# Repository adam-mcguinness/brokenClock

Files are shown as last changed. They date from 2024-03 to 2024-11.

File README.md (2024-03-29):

# Broken Clock IRL

This is an attempt to bring a project by PierreMarTich to life in the real world. After seeing his absolutely "terrible" [project](https://www.reddit.com/r/badUIbattles/comments/r3q1tl/they_say_that_even_a_broken_clock_is_right_twice/) on [r/badUIbattles](https://www.reddit.com/r/badUIbattles/) I knew I needed one on my wall. 

You can find his original project [here](https://github.com/PierreMarTich/Broken_clock) and I must give him full credit for inspiring this idea.
# Code

## Image Generation
Wrote some trash python with a little help from ChatGPT and we are in business.

Vars you can play with:

| Variable Name | Type | Default Value | Description |
|---|---|---|---|
| `style` | bool | `False` | Type of clock design. choose from `'standard'`, `'notch'`, `'cutout'`. |
| `clock_face` | bool | `False` | Enable drawing the clock face. |
| `clock_face_face_color` | string | `'none'` | Not used currently. |
| `clock_face_line_width` | int | `2` | Line width of the clock face edge. |
| `add_quarter_hour_markers` | bool | `True` | Enable drawing quarter-hour markers. |
| `quarter_hour_line_color` | string | `'white'` | Not used currently. |
| `quarter_hour_line_length` | float | `0.1` | Length of the quarter-hour marker lines. |
| `quarter_hour_line_width` | int | `1` | Line width of the quarter-hour markers. |
| `quarter_hour_line_offset` | float | `0.95` | Offset from the center for quarter-hour markers. |
| `add_5_minute_markers` | bool | `False` | Enable drawing 5-minute markers. |
| `five_minute_color` | string | `'white'` | Not used currently. |
| `five_minute_line_length` | float | `0.075` | Length of the 5-minute marker lines. |
| `five_minute_line_width` | float | `0.5` | Line width of the 5-minute markers. |
| `five_minute_line_offset` | float | `0.95` | Offset from the center for 5-minute markers. |
| `add_minute_markers` | bool | `False` | Enable drawing 1-minute markers. |
| `minute_line_color` | string | `'white'` | Color of the minute markers. |
| `minute_line_length` | float | `0.05` | Length of the minute marker lines. |
| `minute_line_width` | float | `0.25` | Line width of the minute markers. |
| `minute_line_offset` | float | `0.95` | Offset from the center for minute markers. |
| `hand_color` | string | `'white'` | Not used currently. |
| `hour_hand_length` | float | `0.5` | Length of the hour hand. |
| `hour_hand_width` | int | `2` | Width of the hour hand. |
| `minute_hand_length` | float | `0.8` | Length of the minute hand. |
| `minute_hand_width` | float | `1.5` | Width of the minute hand. |
| `units` | string | `'mm'` | Measurement units for layout and size. choose from `'inches'`, `'feet'`, `'cm'`, `'mm'`. |
| `grid_rows`, `grid_cols` | int, int | `24, 30` | Number of rows and columns in the grid layout. |
| `clock_diameter` | int | `30` | Diameter of each clock. |
| `spacing` | int | `10` | Spacing between clocks in the grid. |
| `outside_spacing` | int | `20` | Spacing between the dia. of the clock and the cut outline. |
| `background_color` | string | `'black'` | Not used currently. |
| `randomize_clocks` | bool | `False` | Whether to randomize the positions of the clocks. |
| `leds_per_tile` | int | `3` | Number of LEDs per tile in the mapping. |
| `width_in_tiles`, `height_in_tiles` | int, int | Calculated | Width and height of the grid in tiles, calculated. |

This also outputs the required vars and mapping to a .h file for importing to the microcontroller. After shuffling the clocks would be a major PITA to map manually.

Did alot of refactoring and now this outputs a dxf file directly for use with a plotter or laser cutter.

### **Fun Fact**: 
The chance of generating the same clock as someone else is ≈720! or greater than 1 in 2.60e1746. Meaning if you generated one every Planck time from the big bang until the heat death of the universe, you wouldn't even begin to scratch the surface of generating a duplicate. You would need another 10e1596 universe lengths to get there. 
## Arduino Sketch 
The main program is written in arduino for use with the attiny microcontroller. Main features included in the code are:
- saving and importing the LED mapping and Clock indexes from the library generated by the python code.
- 3 buttons for adjusting time with digital display utilizing the clock faces as digits.
  - hour increment button
  - minute increment button
  - second reset button

### Programing

As this is a tinyAVR 2-series, you can use the UPDI port to program the microcontroller with a single pin. There are a few things you need for this, but otherwise it is SUPER easy.
- Some sort of UART or TTL usb to serial connector. I bought [this](https://a.co/d/1Ms2zHJ) one, because usb-c.
- A 4.7kΩ resistor. It's talked about a lot more [here](https://github.com/SpenceKonde/AVR-Guidance/blob/master/UPDI/jtag2updi.md). Basically, I soldered the 4.7kΩ resistor to the TX and RX leads on the board and connected the RX to the UPDI port.  
- [megaTinyCore](https://github.com/SpenceKonde/megaTinyCore)
- Arduino IDE

Steps to flash:
1. Download and install the arduino IDE.
2. Install megaTinyCore, follow [these](https://github.com/SpenceKonde/megaTinyCore/blob/master/Installation.md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) steps.
3. Plug in usb adaptor and check Device Manager (for windows) to find the com port under ports.
4. Right-click on the com device, go to properties, port settings tab, advanced, change Latency Timer to 1.
5. Select your board in the IDE. Tools -> Board -> megaTinyCore -> "ATtiny3224/1624/1614/1604/824/814/804/424/414/404/214/204"
6. Select the com port for your usb adaptor. Tools -> Port -> "your com port from above"
7. Set the programmer this is what I used but might have to play around with it, [see docs](https://github.com/SpenceKonde/AVR-Guidance/blob/master/UPDI/jtag2updi.md#megatinycore). Tools -> Programmer -> "SerialUPDI - 230400 baud"
8. To program hook up the chip to VCC, GND, and the UPDI port to the RX on the programmer.
9. Verify the sketch, and make sure the generated .h file from the python script is in the same directory as the sketch.
10. Upload to the controller. If you are on a new arduino IDE v2 greater, you will need to use Sketch -> Upload Using Programmer.

# Hardware
## Electronics
### Microcontroller
The chosen microcontroller is an Attiny1624. This is the newer series 2 AVR from microchip. This has enough pins to interact with a RTC, 3 buttons for setting time, and control leads to address the LEDs for indicating.
### Real Time Clock
For the RTC I'm going with the accurate DS3231. It is extremely accurate and will only gain or lose about 1 minute a year. For all practical applications assuming you set your clock 2x a year for daylight savings the drift should be minimal. Especially for such an impractical piece of art.

This could also be subbed out for a DS1307 with minimal effort if the DS3231 is too pricey.
### LEDs
For the LEDs I have chosen to go with a 4000k individually addressable 5050 smd LED mounted to a 3x3 matrix pcb to allow tiling and cut down on the production costs while minimizing hand wiring.
## PCBs
### LED Matrix
This is a 3x3 tile that will be able to connect in a modular way to the ones adjacent to it for carry signal and power.

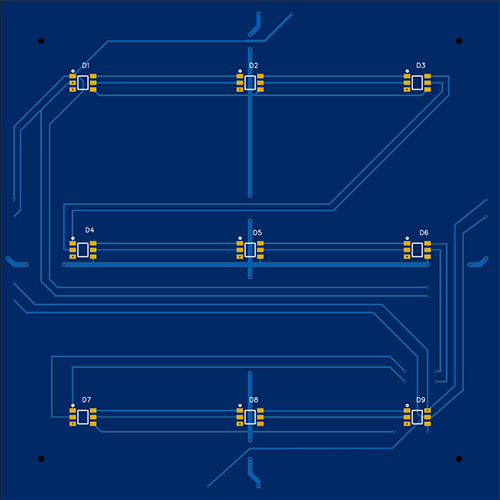
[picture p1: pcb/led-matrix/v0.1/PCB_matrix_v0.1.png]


Gerber files and schematics are available in the pcb folder.

This is v0.1 just ordered for testing. Will add a changelog here.

### Control Board
The control Board has all the other components to make this work microcontroller, RTC, buttons, etc.

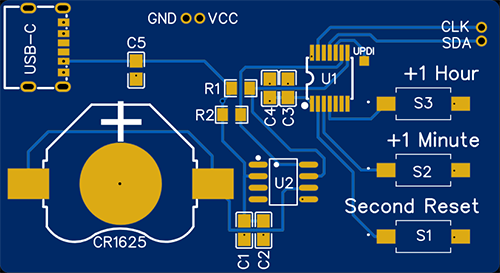
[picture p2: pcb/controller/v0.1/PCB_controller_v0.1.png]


Gerber files and schematics are available in the pcb folder.

This is v0.1 just ordered for testing. Will add a changelog here.
## Display

### Clocks
Still working out what would be best here. The running idea is to use a piece of glass or acrylic to hold a window cling or vinyl sticker for the clock faces. This should allow cheap manufacturing while providing the desired effect.
### Wall Mount/Bracket
Thinking about 3D printed parts to hold the LED Matrix boards, direct the light, and allow for modular connecting.

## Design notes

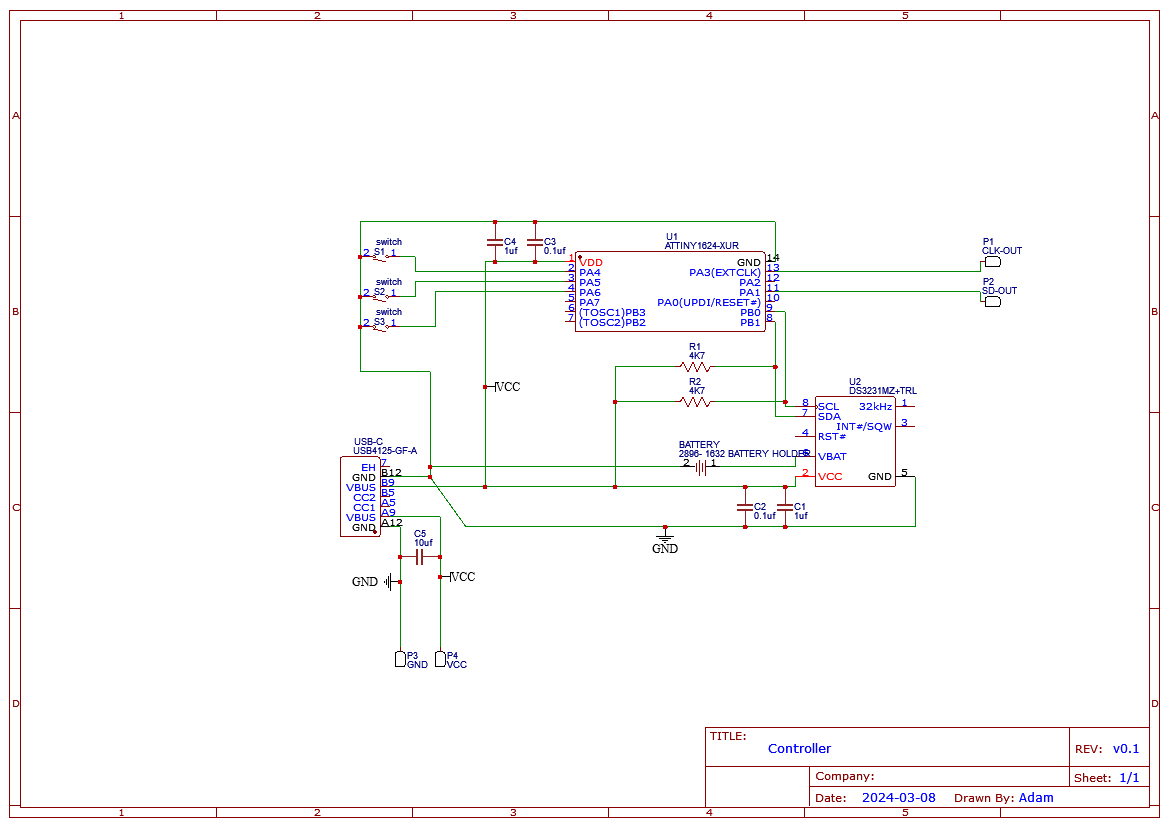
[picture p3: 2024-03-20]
pcb/controller/v0.1/Schematic_controller_v0.1.png

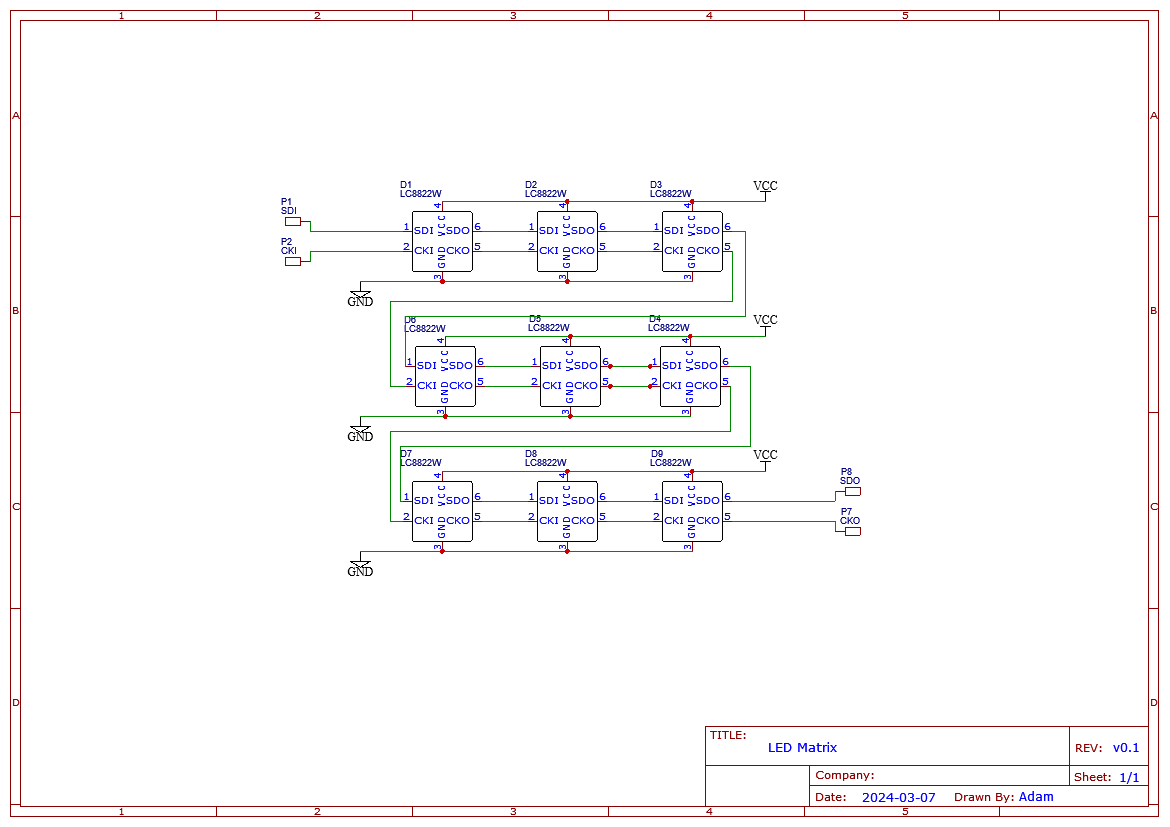
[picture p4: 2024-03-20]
pcb/led-matrix/v0.1/Schematic_matrix_v0.1.png

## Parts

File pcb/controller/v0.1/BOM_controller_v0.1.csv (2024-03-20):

ID | Name | Designator | Quantity | Manufacturer Part | Manufacturer | Supplier | Supplier Part | link
1 | 2896- 1632 BATTERY HOLDER | BATTERY | 1 | 2896 | Keystone Electronics | Digi-Key | C964820 | https://www.digikey.com/en/products/detail/keystone-electronics/2896/9921792
2 | 1uf | C1,C4 | 2 | CL21B105KAFNNNE | Samsung Electro-Mechanics | Digi-Key | 1276-1066-1-ND | https://www.digikey.com/en/products/detail/samsung-electro-mechanics/CL21B105KAFNNNE/3886724
3 | 0.1uf | C2,C3 | 2 | CL21B104KBCNNNC | Samsung Electro-Mechanics | Digi-Key | 1276-1003-1-ND | https://www.digikey.com/en/products/detail/samsung-electro-mechanics/CL21B104KBCNNNC/3886661
4 | 10uf | C5 | 1 | CL21A106KOQNNNE | Samsung Electro-Mechanics | Digi-Key | 1276-1096-1-ND | https://www.digikey.com/en/products/detail/samsung-electro-mechanics/CL21A106KOQNNNE/3886754
5 | 4K7 | R1,R2 | 2 | RC2012F472CS | Samsung Electro-Mechanics | Digi-Key | 1276-5308-1-ND | https://www.digikey.com/en/products/detail/samsung-electro-mechanics/RC2012F472CS/3965615
6 | switch | S1,S2,S3 | 3 | PTS636 SM43 SMTR LFS | C&K | Digi-Key | CKN12310-1-ND | https://www.digikey.com/en/products/detail/c-k/PTS636-SM43-SMTR-LFS/10071723
7 | ATTINY1624-XUR | U1 | 1 | ATTINY1624-XUR | MICROCHIP(美国微芯) | Digi-Key | 150-ATTINY1624-XURCT-ND | https://www.digikey.com/en/products/detail/microchip-technology/ATTINY1624-XUR/12807477
8 | DS3231MZ+TRL | U2 | 1 | DS3231MZ+TRL | Analog Devices Inc./Maxim Integrated | Digi-Key | 175-DS3231MZ+TRLCT-ND | https://www.digikey.com/en/products/detail/analog-devices-inc-maxim-integrated/DS3231MZ-TRL/2754408
9 | USB4125-GF-A | USB-C | 1 | USB4125-GF-A | GCT | Digi-Key | 2073-USB4125-GF-ACT-ND | https://www.digikey.com/en/products/detail/gct/USB4125-GF-A/13547388

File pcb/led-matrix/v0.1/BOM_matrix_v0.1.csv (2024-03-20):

ID | Name | Designator | Quantity | Manufacturer Part | Manufacturer | Supplier | Supplier Part
1 | LC8822W | D1,D2,D3,D4,D5,D6,D7,D8,D9 | 9 | LC8822w | Shenzhen LED Color Co.,LTD | Shenzhen Led Color Co., Ltd. | LC8822x

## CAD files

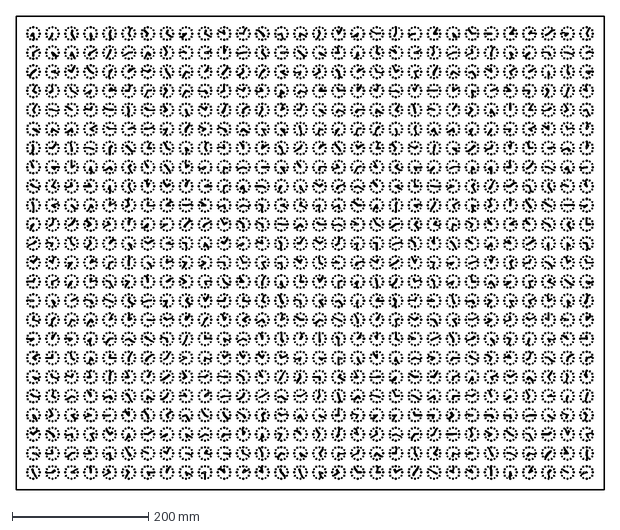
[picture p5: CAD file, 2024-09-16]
720_clocks.dxf
863.0 x 695.0 mm

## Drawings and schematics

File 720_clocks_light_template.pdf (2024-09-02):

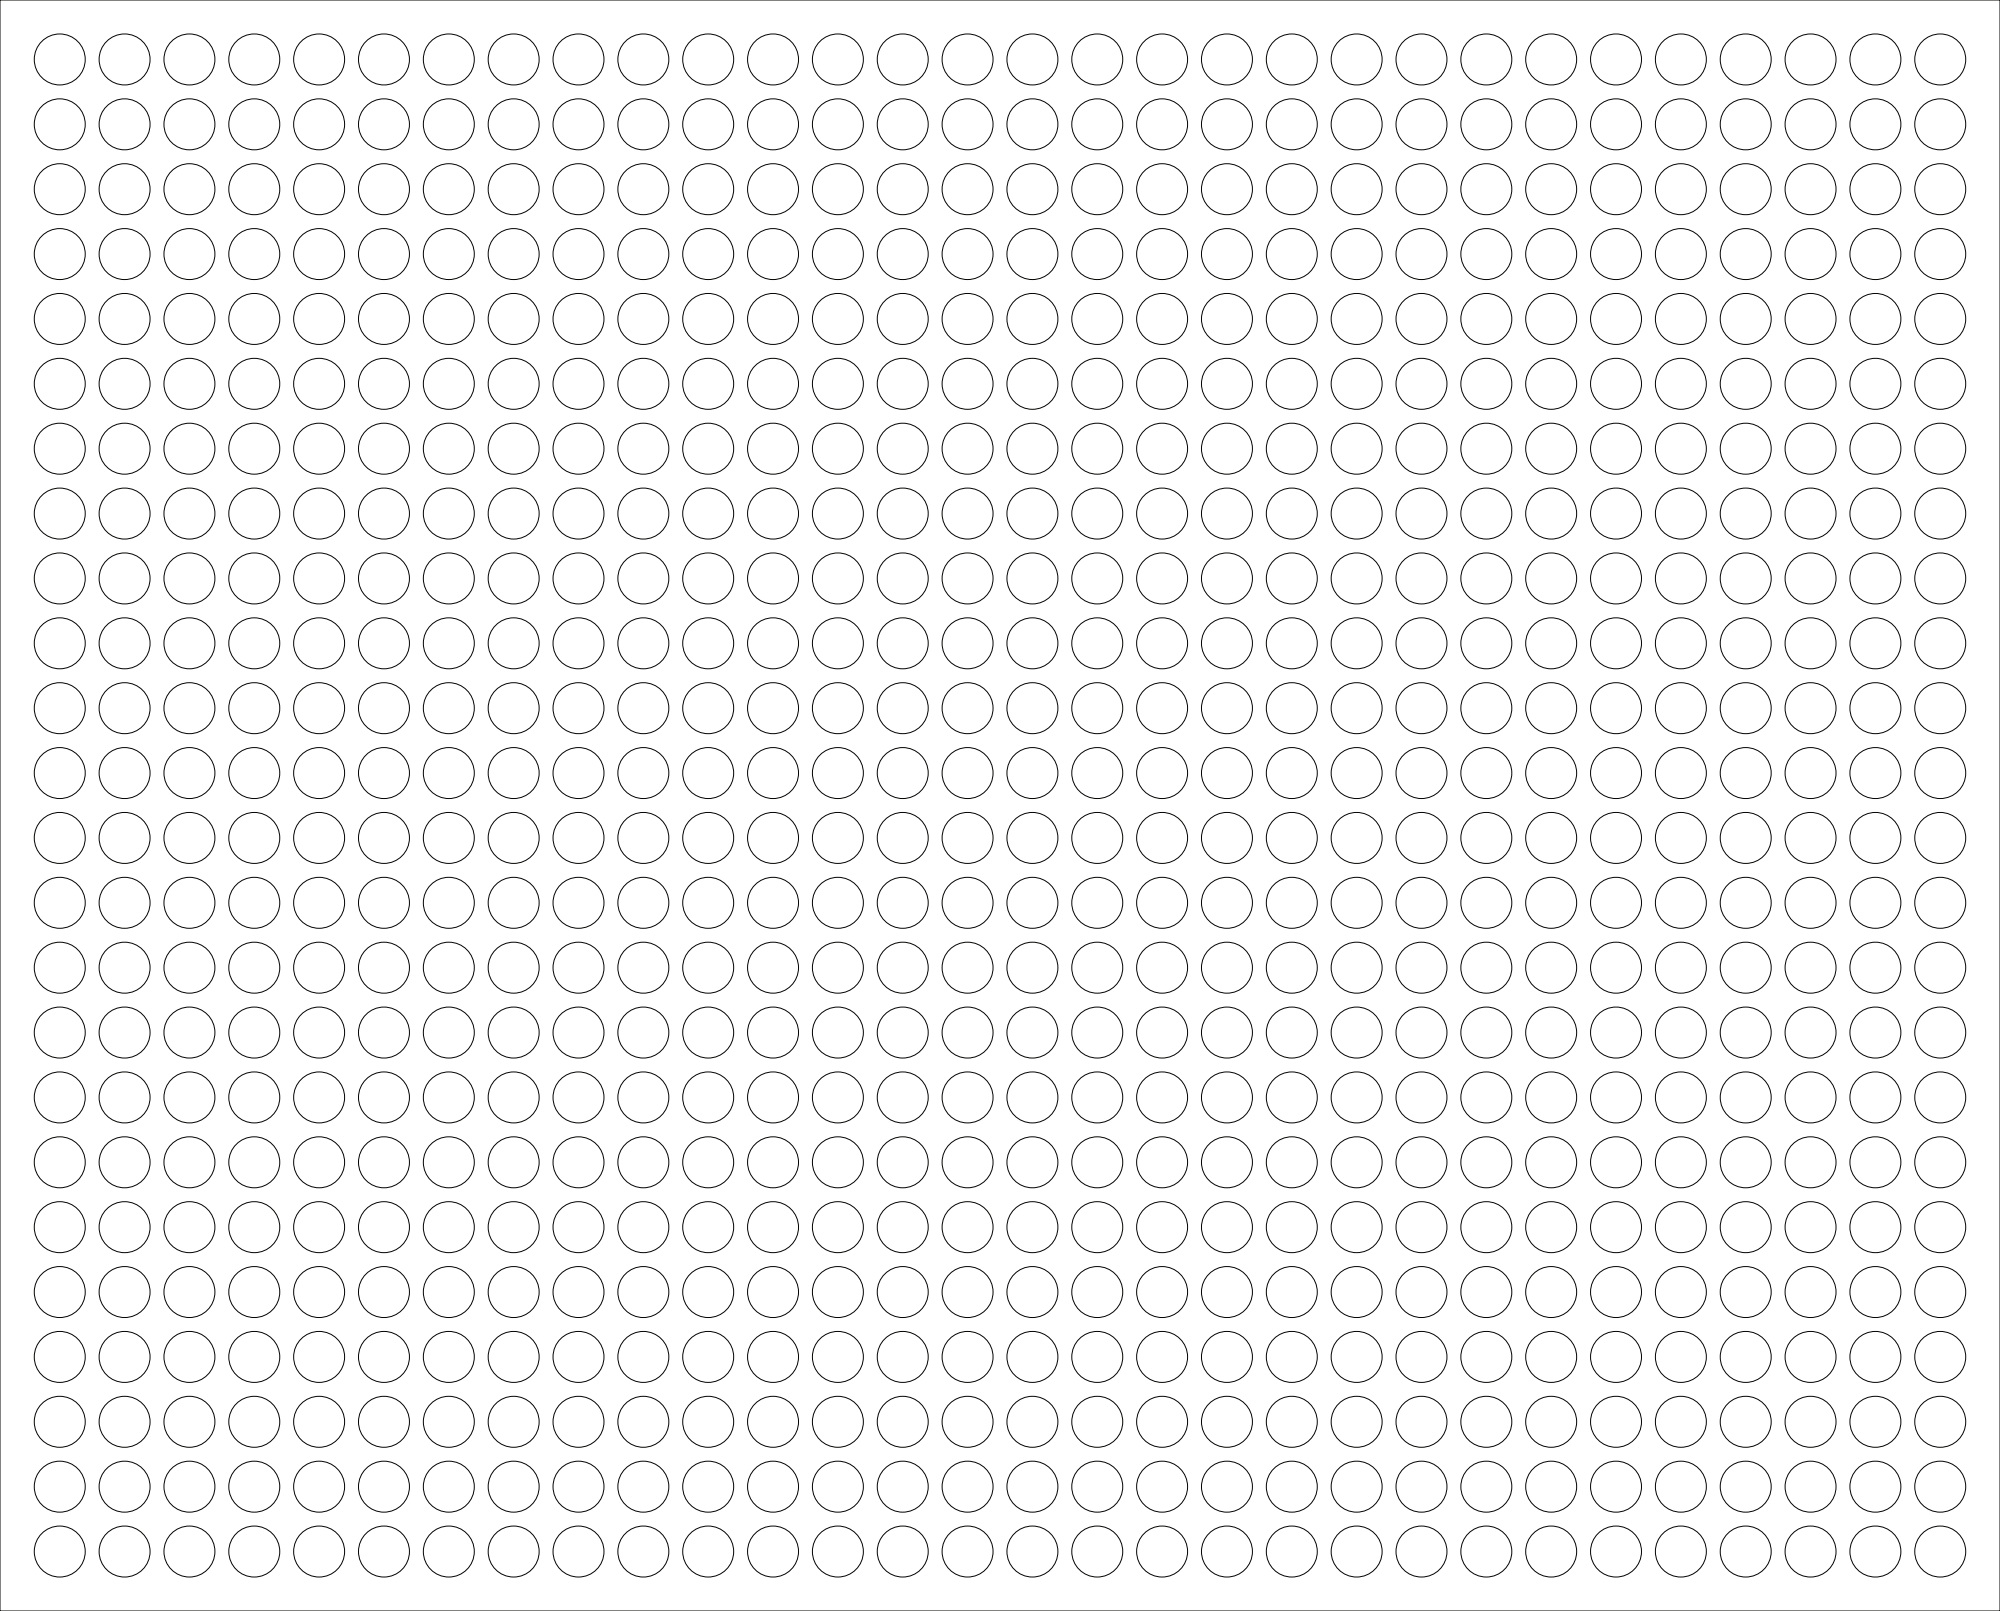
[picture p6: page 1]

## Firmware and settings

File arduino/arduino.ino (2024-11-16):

#include <Wire.h>
#include <SPI.h>
#include <avr/pgmspace.h>
#include <RTClib.h>
#include "led_arrays.h"

#define RTC_ADDRESS 0x68 // I2C address of the RTC
#define NUM_LEDS 720
#define WIDTH_IN_TILES 10
#define HEIGHT_IN_TILES 8

#define HOUR_BUTTON_PIN A6
#define MINUTE_BUTTON_PIN A5
#define SECOND_BUTTON_PIN A4

enum TimeUnit { HOURS, MINUTES, SECONDS };

// Timeout for Time Setting
const unsigned long timeoutDuration = 10000; 

RTC_DS3231 rtc;

bool lastHourButtonState = LOW;
bool lastMinuteButtonState = LOW;
bool lastSecondButtonState = LOW;
bool displayMode = false;

unsigned long lastDebounceTime = 0;
unsigned long debounceDelay = 100;
unsigned long lastModeSwitchTime = 0;

const uint16_t totalRows = 24;
const uint16_t totalColumns = 30;

const bool digitSegmentMap[10][7] = {
    {1, 1, 1, 1, 1, 1, 0}, // 0
    {0, 1, 1, 0, 0, 0, 0}, // 1
    {1, 1, 0, 1, 1, 0, 1}, // 2
    {1, 1, 1, 1, 0, 0, 1}, // 3
    {0, 1, 1, 0, 0, 1, 1}, // 4
    {1, 0, 1, 1, 0, 1, 1}, // 5
    {1, 0, 1, 1, 1, 1, 1}, // 6
    {1, 1, 1, 0, 0, 0, 0}, // 7
    {1, 1, 1, 1, 1, 1, 1}, // 8
    {1, 1, 1, 1, 0, 1, 1}  // 9
};

const uint16_t segmentIndexes[7][5] = {
    {0,1,2, 0xFFFF},       // A
    {2,32, 0xFFFF},        // B
    {62,92,122, 0xFFFF},   // C
    {120,121,122, 0xFFFF}, // D
    {60,90, 0xFFFF},       // E
    {0,30,0xFFFF},         // F
    {60,61,62, 0xFFFF}     // G
};

void setup() {

  SPI.begin();

  pinMode(HOUR_BUTTON_PIN, INPUT_PULLUP);
  pinMode(MINUTE_BUTTON_PIN, INPUT_PULLUP);
  pinMode(SECOND_BUTTON_PIN, INPUT_PULLUP);

  if (!rtc.begin()) {
    Serial.println("RTC failed");
  }
}

void loop() {
    unsigned long currentMillis = millis();

    // Handle button presses for mode switching and time adjustments
    if (digitalRead(HOUR_BUTTON_PIN) == LOW || digitalRead(MINUTE_BUTTON_PIN) == LOW || digitalRead(SECOND_BUTTON_PIN) == LOW) {
        if (currentMillis - lastDebounceTime > debounceDelay) {
            lastDebounceTime = currentMillis;
            lastModeSwitchTime = currentMillis; // Reset timeout timer
            displayMode = true; // Switch to display time mode
            
            // Adjust time based on which button was pressed
            if (digitalRead(HOUR_BUTTON_PIN) == LOW) adjustTime(HOURS);
            else if (digitalRead(MINUTE_BUTTON_PIN) == LOW) adjustTime(MINUTES);
            else if (digitalRead(SECOND_BUTTON_PIN) == LOW) adjustTime(SECONDS);
        }
    }

    // Display logic based on mode
    if (displayMode) {
        displayTime();
        if (currentMillis - lastModeSwitchTime > timeoutDuration) {
            displayMode = false; // Timeout reached, switch back to showing progress mode
        }
    } else {
        DateTime now = rtc.now();
        // Normalize the hour for a 12-hour format (0-11)
        uint8_t hour = now.twelveHour();
        // Calculate total minutes into the 12-hour cycle
        uint16_t minutesIntoCycle = hour * 60 + now.minute();
        // Ensure index wraps around correctly for a 12-hour cycle represented by 720 LEDs
        minutesIntoCycle = minutesIntoCycle % 720; // Ensures wrapping at the end of 12-hour cycle

        if (minutesIntoCycle < NUM_LEDS) {
            int timeMapping = pgm_read_word_near(ledMap + minutesIntoCycle);
            int ledIndex = getLedIndex(timeMapping);
            lightUpLED(ledIndex);
        } else {
            Serial.println("Error: Calculated LED index is out of range.");
        }
    }
}

void lightUpLED(uint16_t index) {
  startFrame();
  // LED Frames
  for (uint16_t i = 0; i < NUM_LEDS; i++) {
    if (i == index) {
      ledOn(1,255,255,255);
    } else {
      ledOff();
    }
  }
  endFrame();
}

void displayTime() {
    DateTime now = rtc.now();
    
    int hour = now.twelveHour();
    int hourTens = hour / 10;
    int hourOnes = hour % 10;
    int minuteTens = now.minute() / 10;
    int minuteOnes = now.minute() % 10;
    int secondTens = now.second() / 10;
    int secondOnes = now.second() % 10;
    
    // Starting indices calculation remains the same
    int digitsAndIndices[][2] = {
        {hourTens, 0},       // Hour tens
        {hourOnes, 4},       // Hour ones
        {minuteTens, 9},     // Minute tens
        {minuteOnes, 13},    // Minute ones
        {secondTens, 18},    // Second tens
        {secondOnes, 22}     // Second ones
    };

    lightUpDigits(digitsAndIndices, 6);
}

void lightUpDigits(const int digits[][2], int numDigits) {
  startFrame();
    
    // LED Frames
    for (uint16_t i = 0; i < NUM_LEDS; i++) {
        bool lightUp = false;
        for (int d = 0; d < numDigits; d++) {
            int digit = digits[d][0];
            uint16_t startIndex = digits[d][1];
            for (int segment = 0; segment < 7; segment++) {
                if (digitSegmentMap[digit][segment]) {
                    for (int j = 0; segmentIndexes[segment][j] != 0xFFFF; j++) {
                        uint16_t originalIndex = segmentIndexes[segment][j];
                        uint16_t adjustedIndex = getLedIndex(startIndex + originalIndex);
                        if (i == adjustedIndex) {
                            lightUp = true;
                            break;
                        }
                    }
                }
                if (lightUp) break;
            }
            if (lightUp) break;
        }
        
        if (lightUp) {
          ledOn(1,10,10,10);
        } else {
          ledOff();
        }
    }
  endFrame();
}


void adjustTime(TimeUnit unit) {
    DateTime now = rtc.now();
    int year = now.year();
    int month = now.month();
    int day = now.day();
    int hour = now.twelveHour();
    int minute = now.minute();
    int second = now.second();
    
    switch (unit) {
        case HOURS:
            hour = (hour + 1) % 24;
            break;
        case MINUTES:
            minute = (minute + 1) % 60;
            break;
        case SECONDS:
            second = 0; // Reset seconds to 0
            break;
    }
    rtc.adjust(DateTime(year, month, day, hour, minute, second));
}

void ledOn(uint8_t brightness, uint8_t red, uint8_t green, uint8_t blue){
  brightness = brightness & 0x1F;
  SPI.transfer(0XE0 | brightness);
  SPI.transfer(blue); // Blue
  SPI.transfer(green); // Green
  SPI.transfer(red); // Red
};

void ledOff(){
  SPI.transfer(0xE0 | 0x00);
  SPI.transfer(0x00);
  SPI.transfer(0x00);
  SPI.transfer(0x00);
};

void startFrame(){
  for (int i = 0; i < 4; i++) {
      SPI.transfer(0x00);
  }
};

void endFrame(){
    for (int i = 0; i < 4; i++) {
      SPI.transfer(0xFF);
  }
};

int getLedIndex(int n) {
    if (n >= 0 && n < NUM_LEDS) { // Assume NUM_LEDS is the total number of LEDs, replace with 720 if constant
        return pgm_read_word_near(matrixMap + n);
    } else {
        return -1; // Return an error code or handle the error as needed
    }
}

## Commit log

2024-03-09 Fixed calcs for inverted y axis
2024-03-12 Changed Print out and a few options.
2024-03-12 Added Arduino Sketch for microcontroller. Adds a var for led_indices_array.h, 3 buttons to change the time with digital display to help with setting. Schematics to come soon.
2024-03-16 Updates to arduino.ino to include led mapping for index.
2024-03-17 Added LED Matrix and controller schematics.
2024-03-19 Changed around the code to facilitate a map for the tile-able led matrix board to avoid long calculations.
    [arduino.ino]
2024-03-19 Added a function to generate a var to map the tile-able led board to the led's actual location.
2024-03-20 Added functions to automatically generate a .h library for the clock index and led mapping based on the number of tiles.
2024-03-20 Added v0.1 schematics, gerber files, boms, and images for the 2 boards that have been ordered.
    [BOM_controller_v0.1.csv, BOM_matrix_v0.1.csv]
2024-03-20 Added spec sheet for led as it is not easily found online.
2024-03-22 Changed to Polygons to facilitate conversion to a CAD format for routing paths with CNC.
2024-03-29 Added outside cut line
2024-04-09 Generated Clock
    [720_clocks.dxf]
2024-09-02 Added Template used to drill light holes in foam.
2024-09-16 This is the clock I am cutting and will program to the controller.
    [720_clocks.dxf]
2024-11-16 Fixed a bug that was lighting up the led in sequence.
    [arduino.ino]
